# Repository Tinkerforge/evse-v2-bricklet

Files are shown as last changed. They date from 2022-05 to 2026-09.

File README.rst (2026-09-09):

EVSE Bricklet 2.0
=================

This Bricklet together with the ESP32 Ethernet Brick and the NFC Bricklet
form the hardware used in the WARP2 Charger.

The Firmware for the EVSE Bricklet 2.0 is also used for the EVSE Bricklet 3.0:
https://github.com/Tinkerforge/evse-v3-bricklet. The hardware version is
run-time detected.

See https://www.warp-charger.com/ for more details about WARP Charger.

This repository contains the firmware source code and the hardware design
files. The documentation generator configs can be found at
https://github.com/Tinkerforge/generators

.. BEGIN WARP REPOSITORIES (managed block, generated from esp32-firmware/repo_overview.rst - do not edit by hand, run update_repo_overview.py instead)

WARP Repositories
-----------------

This is an overview of all repositories that make up the WARP Charger and
WARP Energy Manager ecosystem.

Please report **any** issue concerning WARP hard- or software in the
`esp32-firmware`_ repository, no matter which repository it originates from.

Software
~~~~~~~~

- `esp32-firmware`_ - Source code of the ESP32 firmware shared between all WARP Chargers and Energy Managers

Libraries used by the firmware:

- `tfjson`_ - SAX style JSON serializer and deserializer
- `tfnetwork`_ - Modbus TCP server and client implementation
- `tfocpp`_ - OCPP 1.6 implementation
- `tftools`_ - Miscellaneous tools and helpers

Remote access:

- `esp32-remote-access`_ - Source code of the my.warp-charger.com remote access server

Documentation, tools and integrations:

- `warp-charger`_ - Source code of (docs.)warp-charger.com and the printed manual, released firmwares, datasheets and documents, as well as some tools and hardware design files
- `api.warp-charger.com`_ - Serves APIs that are used by WARP Chargers to obtain relevant public information like day ahead prices
- `vislog.warp-charger.com`_ - Visualizes WARP Charger logs and EVSE debug protocols
- `dbus-warp-charger`_ - Integrates WARP Chargers into a Victron Energy Venus OS device (e.g. Cerbo GX)

WARP Charger Hardware
~~~~~~~~~~~~~~~~~~~~~~

WARP4 Charger
"""""""""""""

*Current charger generation.*

- `warp-esp32-ethernet-v2-brick`_ - Hardware design files of the WARP ESP32 Ethernet Brick 2.0
- `warp-esp32-ethernet-v2-co-bricklet`_ - Firmware source code of the WARP ESP32 Ethernet 2.0 Co Bricklet (co-processor)
- `evse-v4-bricklet`_ - Hardware design files of the EVSE 4.0 Bricklet (firmware shared with the EVSE 2.0 Bricklet)
- `nfc-bricklet`_ - Firmware source code and hardware design files of the NFC Bricklet

WARP3 Charger
"""""""""""""

- `warp-esp32-ethernet-brick`_ - Hardware design files of the WARP ESP32 Ethernet Brick
- `evse-v3-bricklet`_ - Hardware design files of the EVSE 3.0 Bricklet (firmware shared with the EVSE 2.0 Bricklet)
- `nfc-bricklet`_ - Firmware source code and hardware design files of the NFC Bricklet

WARP2 Charger
"""""""""""""

- `esp32-ethernet-brick`_ - Hardware design files of the ESP32 Ethernet Brick
- `evse-v2-bricklet`_ - Firmware source code and hardware design files of the EVSE 2.0 Bricklet
- `nfc-bricklet`_ - Firmware source code and hardware design files of the NFC Bricklet

WARP1 Charger
"""""""""""""

- `esp32-brick`_ - Hardware design files of the ESP32 Brick
- `evse-bricklet`_ - Firmware source code and hardware design files of the EVSE Bricklet
- `rs485-bricklet`_ - Firmware source code and hardware design files of the RS485 Bricklet

WARP Energy Manager Hardware
~~~~~~~~~~~~~~~~~~~~~~~~~~~~~~

WARP Energy Manager 2.0
"""""""""""""""""""""""

*Current energy manager generation.*

- `esp32-ethernet-brick`_ - Hardware design files of the ESP32 Ethernet Brick
- `warp-energy-manager-v2-bricklet`_ - Firmware source code and hardware design files of the WARP Energy Manager 2.0 Bricklet
- `warp-front-panel-bricklet`_ - Firmware source code and hardware design files of the WARP Front Panel Bricklet

WARP Energy Manager 1.0
"""""""""""""""""""""""

- `esp32-ethernet-brick`_ - Hardware design files of the ESP32 Ethernet Brick
- `warp-energy-manager-bricklet`_ - Firmware source code and hardware design files of the WARP Energy Manager Bricklet

Forked/patched projects
~~~~~~~~~~~~~~~~~~~~~~~~~

- `arduino-esp32`_
- `esp32-arduino-libs`_
- `WireGuard-ESP32-Arduino`_

.. Link targets: One definition per repository, keep in sync with the lists above.

.. _esp32-firmware: https://github.com/Tinkerforge/esp32-firmware
.. _tfjson: https://github.com/Tinkerforge/tfjson
.. _tfnetwork: https://github.com/Tinkerforge/tfnetwork
.. _tfocpp: https://github.com/Tinkerforge/tfocpp
.. _tftools: https://github.com/Tinkerforge/tftools
.. _esp32-remote-access: https://github.com/Tinkerforge/esp32-remote-access
.. _warp-charger: https://github.com/Tinkerforge/warp-charger
.. _api.warp-charger.com: https://github.com/Tinkerforge/api.warp-charger.com
.. _vislog.warp-charger.com: https://github.com/Tinkerforge/vislog.warp-charger.com
.. _dbus-warp-charger: https://github.com/Tinkerforge/dbus-warp-charger
.. _warp-esp32-ethernet-v2-brick: https://github.com/Tinkerforge/warp-esp32-ethernet-v2-brick
.. _warp-esp32-ethernet-v2-co-bricklet: https://github.com/Tinkerforge/warp-esp32-ethernet-v2-co-bricklet
.. _evse-v4-bricklet: https://github.com/Tinkerforge/evse-v4-bricklet
.. _nfc-bricklet: https://github.com/Tinkerforge/nfc-bricklet
.. _warp-esp32-ethernet-brick: https://github.com/Tinkerforge/warp-esp32-ethernet-brick
.. _evse-v3-bricklet: https://github.com/Tinkerforge/evse-v3-bricklet
.. _esp32-ethernet-brick: https://github.com/Tinkerforge/esp32-ethernet-brick
.. _evse-v2-bricklet: https://github.com/Tinkerforge/evse-v2-bricklet
.. _esp32-brick: https://github.com/Tinkerforge/esp32-brick
.. _evse-bricklet: https://github.com/Tinkerforge/evse-bricklet
.. _rs485-bricklet: https://github.com/Tinkerforge/rs485-bricklet
.. _warp-energy-manager-v2-bricklet: https://github.com/Tinkerforge/warp-energy-manager-v2-bricklet
.. _warp-front-panel-bricklet: https://github.com/Tinkerforge/warp-front-panel-bricklet
.. _warp-energy-manager-bricklet: https://github.com/Tinkerforge/warp-energy-manager-bricklet
.. _arduino-esp32: https://github.com/Tinkerforge/arduino-esp32
.. _esp32-arduino-libs: https://github.com/Tinkerforge/esp32-arduino-libs
.. _WireGuard-ESP32-Arduino: https://github.com/Tinkerforge/WireGuard-ESP32-Arduino

.. END WARP REPOSITORIES

Repository Content
------------------

software/:
 * examples/: Examples for all supported languages
 * build/: Compiled files
 * src/: Source code of firmware
 * Makefile: Makefile to build project

hardware/:
 * Contains KiCad project files and additionally schematics as PDF

datasheets/:
 * Contains datasheets for sensors and complex ICs that are used

Hardware
--------

The hardware is designed with the open source EDA Suite KiCad
(http://www.kicad.org). Before you are able to open the files,
you have to install the Tinkerforge kicad-libraries
(https://github.com/Tinkerforge/kicad-libraries). You can either clone
them directly in hardware/ or clone them in a separate folder and
symlink them into hardware/
(ln -s kicad_path/kicad-libraries project_path/hardware). After that you
can open the .pro file in hardware/ with KiCad and from there view and
modify the schematics and the PCB layout.

Software
--------

If you want to do your own Brick/Bricklet firmware development we highly
recommend that you use our build environment setup script and read the
tutorial (https://www.tinkerforge.com/en/doc/Tutorials/Tutorial_Build_Environment/Tutorial.html).

To compile the C code we recommend you to install the newest GNU Arm Embedded
Toolchain (https://launchpad.net/gcc-arm-embedded/+download).
You also need to install bricklib2 (https://github.com/Tinkerforge/bricklib2).

You can either clone it directly in software/src/ or clone it in a
separate folder and symlink it into software/src/
(ln -s bricklib_path/bricklib2 project_path/software/src/). Finally make sure to
have CMake installed (http://www.cmake.org/cmake/resources/software.html).

After that you can build the firmware by invoking make in software/.
The firmware (.zbin) can then be found in software/build/ and uploaded
with brickv (click button "Flashing" on start screen).

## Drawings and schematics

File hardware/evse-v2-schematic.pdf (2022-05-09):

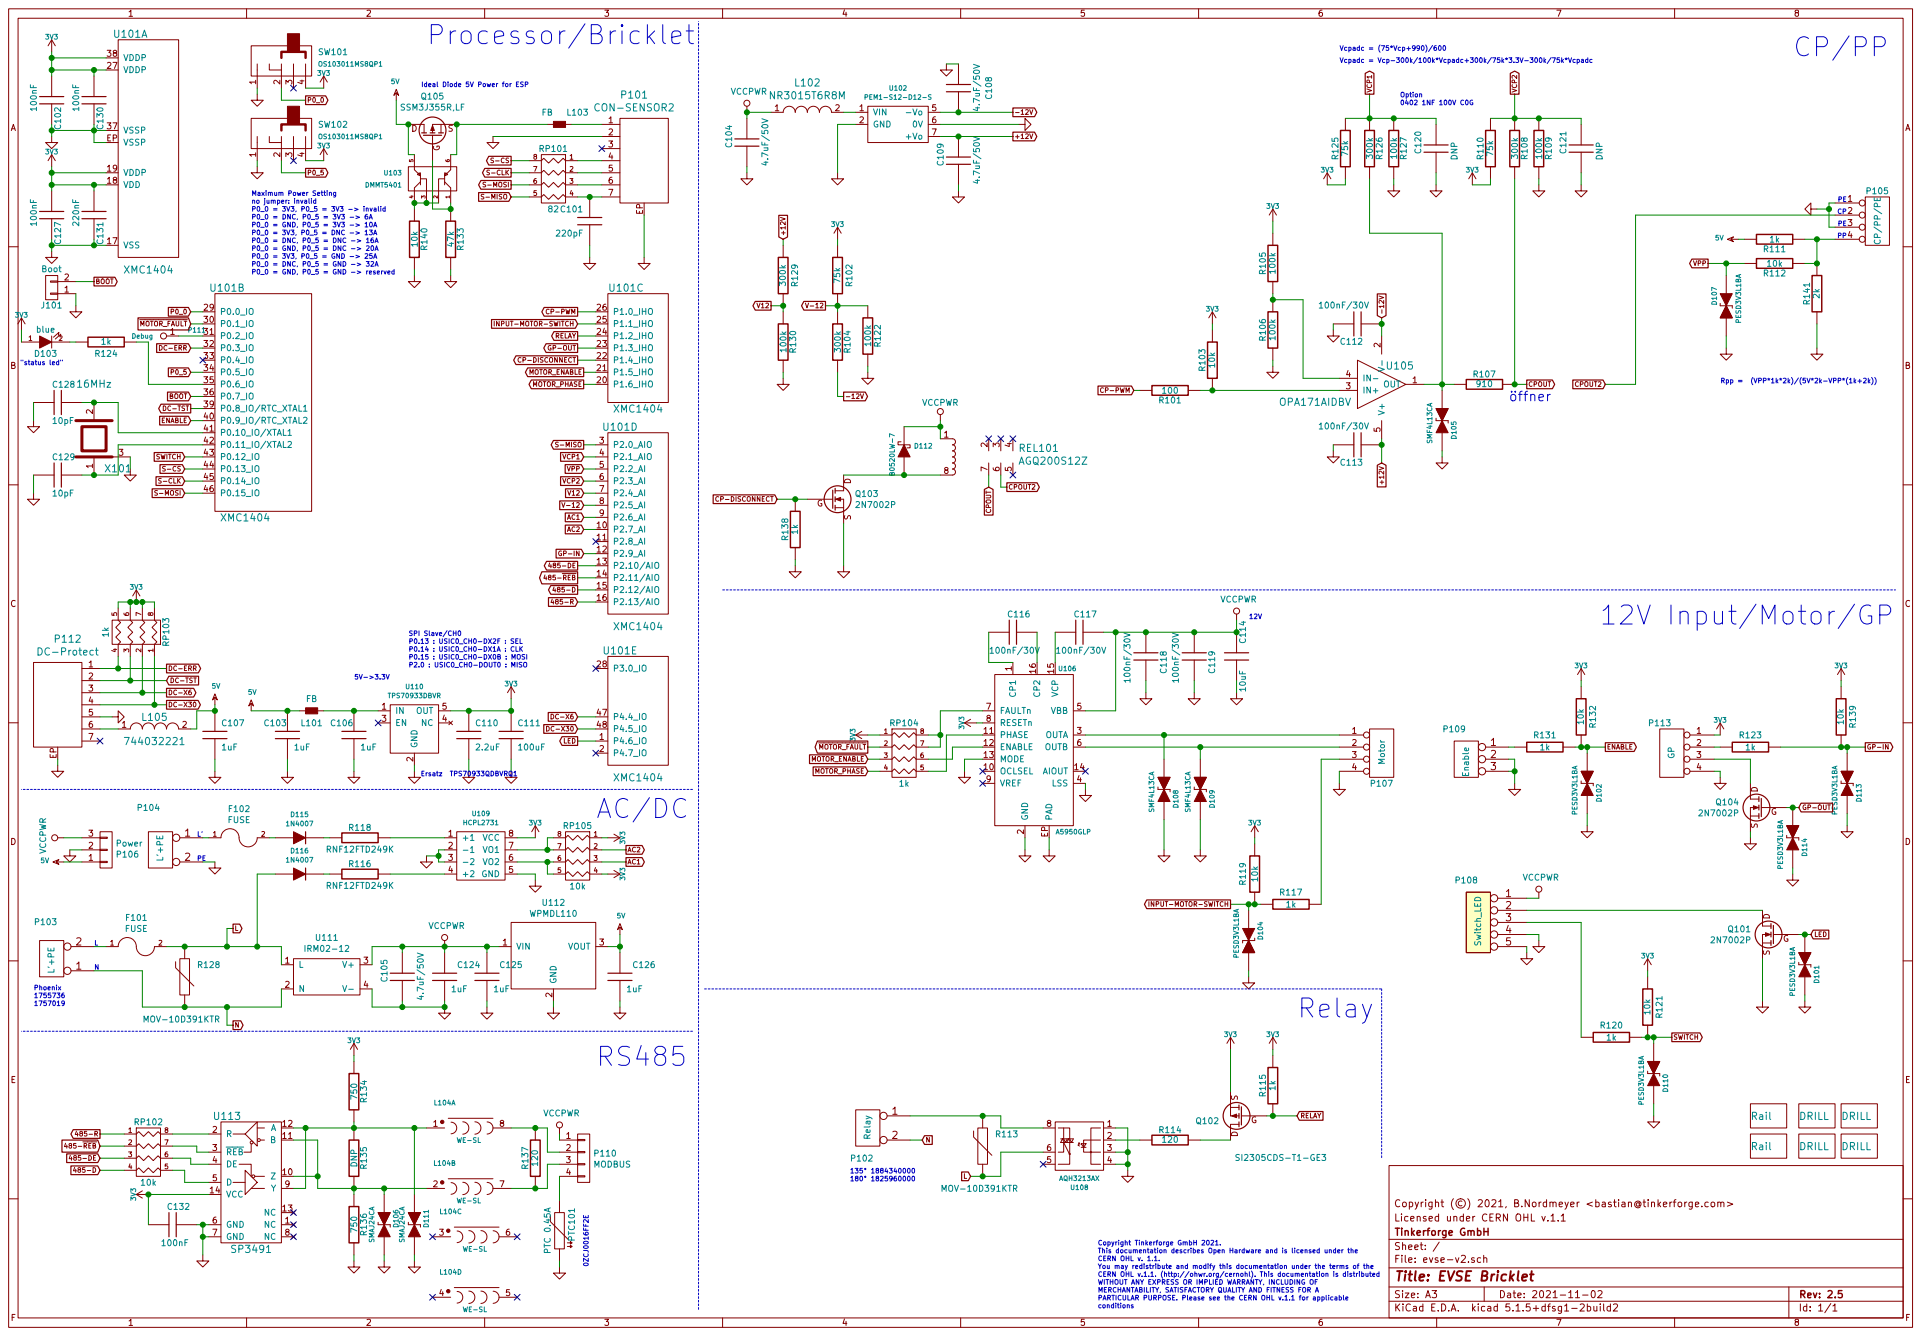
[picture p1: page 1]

Vcpadc = (75*Vcp+990)/600 Option
Vcpadc = Vcp-300k/100k*Vcpadc+300k/75k*3.3V-300k/75k*Vcpadc

Licensed under CERN OHL v.1.1 Copyright (©) 2021, B.Nordmeyer <bastian@tinkerforge.com> C130100nF

Ideal Diode 5V Power for ESP

Maximum Power Setting
no jumper: invalid P0_0 = 3V3, P0_5 = 3V3 -> invalid P0_0 = DNC, P0_5 = 3V3 -> 6A

CP-DISCONNECT

1 OCLSEL 10 PHASE 11 ENABLE 12 MODE 13 AIOUT 14 VCP 15 CP2 16 GND

Id: 1/1 Title: EVSE Bricklet File: evse-v2.sch Sheet: / Tinkerforge GmbH

Copyright Tinkerforge GmbH 2021. This documentation describes Open Hardware and is licensed under the CERN OHL v. 1.1. You may redistribute and modify this documentation under the terms of the CERN OHL v.1.1. (http://ohwr.org/cernohl). This documentation is distributed WITHOUT ANY EXPRESS OR IMPLIED WARRANTY, INCLUDING OF MERCHANTABILITY, SATISFACTORY QUALITY AND FITNESS FOR A

PARTICULAR PURPOSE. Please see the CERN OHL v.1.1 for applicable
conditions

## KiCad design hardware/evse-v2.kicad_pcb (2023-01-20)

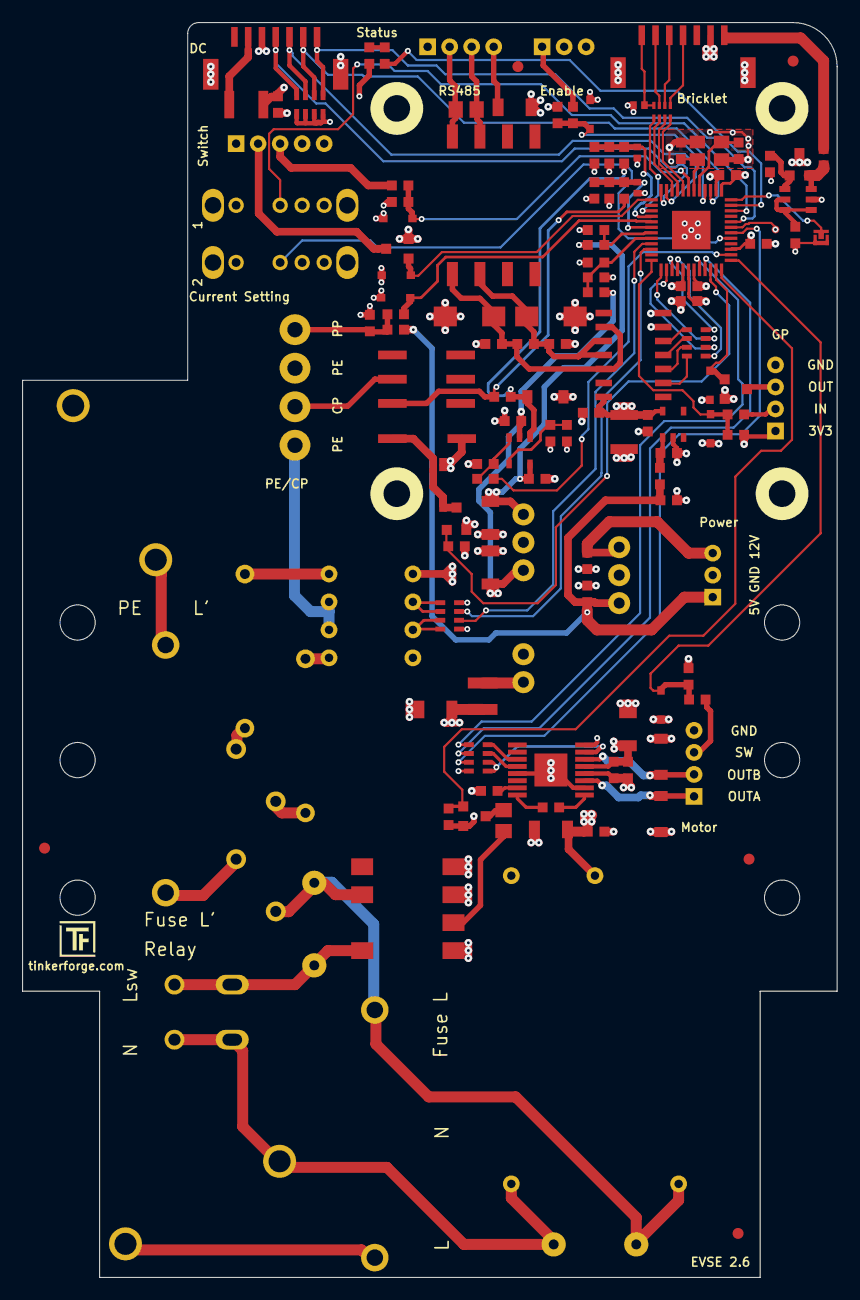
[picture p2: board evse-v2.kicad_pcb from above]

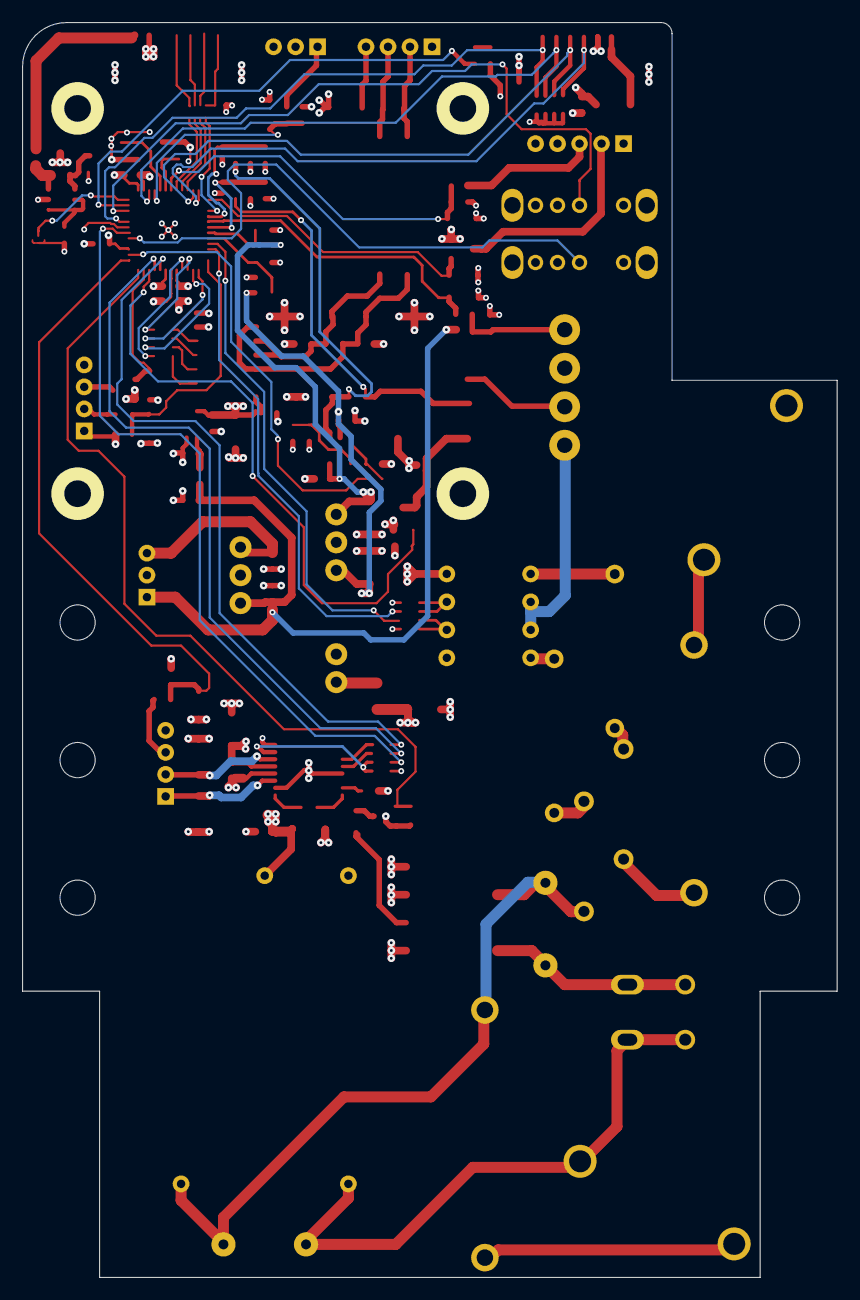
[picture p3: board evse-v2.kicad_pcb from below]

Board: 4 copper layers, 74.0 x 114.0 mm, 144 parts (2 on the bottom side), 100 nets.

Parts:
A101, A102, A103, A104: DRILL; DRILL_NP_35
A105, A106: Rail; din-rail-mount
C101: 220pF; C0402F
C102, C127, C130, C132: 100nF; C0603F
C103, C106, C107, C124, C125, C126: 1uF; C0603F
C104, C105, C108, C109: 4.7uF/50V; C1206
C110: 2.2uF; C0603F
C111: 100uF; C1210
C112, C113, C116, C117, C118, C119: 100nF/30V; C0603F
C114: 10uF; C1206
C120, C121: DNP; C0402F
C128, C129: 10pF; C0603F
C131: 220nF; C0603F
D101, D102, D104, D107, D110, D113, D114: ‎PESD3V3L1BA; SOD-323
D103: blue; D0603F
D105, D108, D109: SMF4L13CA; SOD-123FL
D106, D111: SMAJ24CA; DO-214AC
D112: B0520LW-7; SOD-123
D115, D116: 1N4007; DO-41
F101, F102: FUSE; Fuse-Holder-5x20
Fiducial_Mark: VAL**; Fiducial_Mark
Fiducial_Mark#2, Fiducial_Mark#3, Fiducial_Mark#4, Fiducial_Mark#5: VAL**; Fiducial_Mark
J101: Boot; SolderJumper
L101, L103: FB; R0603F
L102: NR3015T6R8M; NR3030
L104: WE-SL
P101: CON-SENSOR2; CON-SENSOR2_180
P102: Relay; LSF-SMT-500-02-135
P103, P104: L'+PE; wm_2491620000
P105: CP/PP/PE; OQ_4P_Vertical
P106: Power; JST-PH-3-THT
P107: Motor; JST-PH-4-THT
P108: Switch_LED; JST-PH-5-THT
P109: Enable; JST-PH-3-THT
P110: MODBUS; JST-PH-4-THT
P111: Debug; DEBUG_PAD
P112: DC-Protect; CON-SENSOR2_180
P113: GP; JST-PH-4-THT
PTC101: PTC 0.45A; C1206
Q101, Q103, Q104: 2N7002P; SOT23GDS
Q102: SI2305CDS-T1-GE3; SOT23GDS
Q105: SSM3J355R,LF; SOT23GDS
R1: 0; R1210
R101: 100; R0603F
R102, R110, R125: 75k; R0603F
R103, R112, R119, R121, R132, R139, R140: 10k; R0603F
R104, R108, R126, R129: 300k; R0603F
R105, R106, R109, R122, R127, R130: 100k; R0603F
R107: 910; R0603F
R111, R115, R117, R120, R123, R124, R131, R138: 1k; R0603F
R113, R128: MOV-10D391KTR; VAR_10mm
R114, R137: 120; R0805E
R116, R118: RNF12FTD249K; RNF12-2
R133: 47k; R0603F
R134, R136: 750; R0603F
R135: DNP; R0603F
R141: 2k; R0603F
REL101: AGQ200S12Z; AGQ2X0
RP101: 82; 4X0402
RP102: 10k; 0603X4
RP103, RP104: 1k; 4X0603
RP105: 10k; 4X0603
SW101, SW102: OS103011MS8QP1
U101: XMC1404; QFN48-EP2
U102: PEM1-S12-D12-S; PEM1S
U103: DMMT5401; SOT26
U105: OPA171AIDBV; SOT23-5
U106: A5950GLP; TSSOP16_EP
U108: AQH3213AX; AQ-H
U109: HCPL2731; DIP-8
U110: TPS70933DBVR; SOT23-5
U111: IRM02-12; IRM02
U112: WPMDL110
U113: SP3491; SOIC-14_3.9x8.7mm_Pitch1.27mm
X101: 16MHz; CRYSTAL_3225

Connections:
3V3: C102.1, C110.1, C111.1, C127.1, C130.1, C131.1, C132.2, D103.1 (A), P113.1, Q102.S, R102.2, R103.2, R105.2, R110.1, R115.2, R119.2, R121.2, R125.1, R132.2, R134.1, R139.2, RP103.5 (R4), RP103.6 (R3), RP103.7 (R2), RP103.8 (R1), RP104.1, RP105.1, RP105.4, SW101.4, SW102.4, U101.18 (VDD), U101.19 (VDDP), U101.27 (VDDP), U101.38 (VDDP), U106.8 (RESETn), U109.8 (VCC), U110.5 (OUT), U113.14 (VCC)
5V: C103.1, C107.1, C126.1, L101.2, P106.1, Q105.D, R1.1, R111.2, U103.5, U112.3 (VOUT)
485-D: RP102.4, U101.15 (P2.12/AIO)
485-DE: RP102.3, U101.13 (P2.10/AIO)
485-R: RP102.1, U101.16 (P2.13/AIO)
485-~REB: RP102.2, U101.14 (P2.11/AIO)
+12V: C109.1, C113.2, R129.2, U102.7 (+Vo), U105.5 (V+)
-12V: C108.2, C112.2, R104.2, U102.5 (-Vo), U105.2 (V-)
AC1: RP105.3, U101.9 (P2.6_AI)
AC2: RP105.2, U101.10 (P2.7_AI)
BOOT: J101.2, U101.36 (P0.7_IO)
CP-DISCONNECT: Q103.G, R138.2, U101.22 (P1.4_IHO)
CP-PWM: R101.2, U101.26 (P1.0_IHO)
CPOUT: R107.2, R108.2, REL101.7
CPOUT2: P105.2, REL101.6
DC-ERR: P112.1, RP103.4, U101.32 (P0.3_IO)
DC-TST: P112.2, RP103.3, U101.39 (P0.8_IO/RTC_XTAL1)
DC-X6: P112.3, RP103.2, U101.47 (P4.4_IO)
DC-X30: P112.4, RP103.1, U101.48 (P4.5_IO)
ENABLE: D102.1 (A), R131.1, R132.1, U101.40 (P0.9_IO/RTC_XTAL2)
GND: C101.2, C102.2, C103.2, C104.2, C105.2, C106.2, C107.2, C108.1, C109.2, C110.2, C111.2, C112.1, C113.1, C114.2, C118.1, C119.1, C120.2, C121.2, C124.2, C125.2, C126.2, C127.2, C128.2, C129.2, C130.2, C131.2, C132.1, D101.2 (K), D102.2 (K), D104.1 (A), D105.2 (K), D106.2 (K), D107.1 (A), D108.2 (K), D109.2 (K), D110.2 (K), D111.2 (K), D113.2 (K), D114.2 (K), J101.1, P101.2, P101.EP, P104.2 (PM), P105.1, P105.3, P106.2, P107.4, P108.4, P108.5, P109.2 (PM), P109.3, P112.5, P112.EP, P113.4, PTC101.2, Q101.S, Q103.S, Q104.S, R106.1, R109.2, R122.2, R127.2, R130.2, R133.1, R136.2, R138.1, R140.1, R141.1, SW101.1, SW102.1, U101.17 (VSS), U101.37 (VSSP), U101.EP (VSSP), U102.2 (GND), U102.6 (0V), U106.2 (GND), U106.4 (LSS), U106.13 (MODE), U106.EP (PAD), U108.1, U108.3, U108.4, U109.2 (-1), U109.3 (-2), U109.5 (GND), U110.2 (GND), U111.4 (V-), U112.2 (GND), U113.6 (GND), U113.7 (GND), X101.3
GP-IN: D113.1 (A), R123.1, R139.1, U101.12 (P2.9_AI)
GP-OUT: D114.1 (A), Q104.G, U101.23 (P1.3_IHO)
INPUT-MOTOR-SWITCH: D104.2 (K), R117.1, R119.1, U101.25 (P1.1_IHO)
L: D116.1 (A), F101.2, R113.2, R128.1, U108.6, U111.1 (L)
LED: D101.1 (A), Q101.G, U101.1 (P4.6_IO)
MOTOR_ENABLE: RP104.3, U101.21 (P1.5_IHO)
MOTOR_PHASE: RP104.4, U101.20 (P1.6_IHO)
N: P102.2 (PM), P103.1, R128.2, U111.2 (N)
unnamed: C101.1, P101.7, RP101.4
unnamed: C106.1, L101.1, U110.1 (IN)
unnamed: C116.1, U106.16 (CP2)
unnamed: C116.2, U106.1 (CP1)
unnamed: C117.2, U106.15 (VCP)
unnamed: C128.1, U101.41 (P0.10_IO/XTAL1), X101.2
unnamed: C129.1, U101.42 (P0.11_IO/XTAL2), X101.1
unnamed: D103.2 (K), R124.2
unnamed: D105.1 (A), R107.1, R126.2, U105.1 (OUT)
unnamed: D106.1 (A), L104.2, R135.2, R136.1, U113.10 (Z), U113.11 (B)
unnamed: D108.1 (A), P107.1, U106.3 (OUTA)
unnamed: D109.1 (A), P107.2, U106.6 (OUTB)
unnamed: D111.1 (A), L104.1, R134.2, R135.1, U113.9 (Y), U113.12 (A)
unnamed: D112.1 (A), Q103.D, REL101.8
unnamed: D115.1 (A), F102.2
unnamed: D115.2 (K), R118.1
unnamed: D116.2 (K), R116.1
unnamed: F101.1, P103.2 (PM)
unnamed: F102.1, P104.1
unnamed: L102.2, U102.1 (VIN)
unnamed: L103.1, Q105.S, U103.6
unnamed: L103.2, P101.1
unnamed: L104.7, P110.3, R137.1
unnamed: L104.8, P110.2, R137.2
unnamed: P101.4, RP101.1
unnamed: P101.5, RP101.2
unnamed: P101.6, RP101.3
unnamed: P102.1, R113.1, U108.8
unnamed: P105.4, R111.1, R112.1, R141.2
unnamed: P107.3, R117.2
unnamed: P108.2, Q101.D
unnamed: P108.3, R120.2
unnamed: P109.1, R131.2
unnamed: P110.4, PTC101.1
unnamed: P111.1, U101.31 (P0.2_IO)
unnamed: P112.6, R1.2
unnamed: P113.2, R123.2
unnamed: P113.3, Q104.D
unnamed: Q102.D, R114.1
unnamed: Q105.G, R133.2, U103.1
unnamed: R101.1, R103.1, U105.3 (IN+)
unnamed: R105.1, R106.2, U105.4 (IN-)
unnamed: R114.2, U108.2
unnamed: R116.2, U109.4 (+2)
unnamed: R118.2, U109.1 (+1)
unnamed: R124.1, U101.35 (P0.6_IO)
unnamed: R140.2, U103.2, U103.3, U103.4
unnamed: RP102.5 (R4), U113.5 (D)
unnamed: RP102.6 (R3), U113.4 (DE)
unnamed: RP102.7 (R2), U113.3 (~REB)
unnamed: RP102.8 (R1), U113.2 (R)
unnamed: RP104.5 (R4), U106.11 (PHASE)
unnamed: RP104.6 (R3), U106.12 (ENABLE)
unnamed: RP104.7 (R2), RP104.8 (R1), U106.7 (FAULTn)
unnamed: RP105.5 (R4), RP105.6 (R3), U109.6 (VO2)
unnamed: RP105.7 (R2), RP105.8 (R1), U109.7 (VO1)
P0_0: SW101.2, U101.29 (P0.0_IO)
P0_5: SW102.2, U101.34 (P0.5_IO)
RELAY: Q102.G, R115.1, U101.24 (P1.2_IHO)
S-CLK: RP101.7 (R2), U101.45 (P0.14_IO)
S-CS: RP101.8 (R1), U101.44 (P0.13_IO)
S-MISO: RP101.5 (R4), U101.3 (P2.0_AIO)
S-MOSI: RP101.6 (R3), U101.46 (P0.15_IO)
SWITCH: D110.1 (A), R120.1, R121.1, U101.43 (P0.12_IO)
V12: R129.1, R130.1, U101.7 (P2.4_AI)
V-12: R102.1, R104.1, R122.1, U101.8 (P2.5_AI)
VCC: C104.1, C105.1, C114.1, C117.1, C118.2, C119.2, C124.1, C125.1, D112.2 (K), L102.1, P106.3, P108.1, P110.1, REL101.1, U106.5 (VBB), U111.3 (V+), U112.1 (VIN)
VCP1: C120.1, R125.2, R126.1, R127.1, U101.4 (P2.1_AIO)
VCP2: C121.1, R108.1, R109.1, R110.2, U101.6 (P2.3_AI)
VPP: D107.2 (K), R112.2, U101.5 (P2.2_AI)
~MOTOR_FAULT: RP104.2, U101.30 (P0.1_IO)

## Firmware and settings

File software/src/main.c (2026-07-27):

/* evse-v2-bricklet
 * Copyright (C) 2021 Olaf Lüke <olaf@tinkerforge.com>
 *
 * main.c: Initialization for EVSE Bricklet 2.0
 *
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
 * You should have received a copy of the GNU Lesser General Public
 * License along with this library; if not, write to the
 * Free Software Foundation, Inc., 59 Temple Place - Suite 330,
 * Boston, MA 02111-1307, USA.
 */

#include <stdio.h>
#include <stdbool.h>

#include "configs/config.h"

#include "bricklib2/bootloader/bootloader.h"
#include "bricklib2/hal/system_timer/system_timer.h"
#include "bricklib2/logging/logging.h"
#include "bricklib2/warp/rs485.h"
#include "bricklib2/warp/meter.h"
#include "bricklib2/warp/contactor_check.h"
#include "communication.h"

#include "evse.h"
#include "iec61851.h"
#include "lock.h"
#include "led.h"
#include "button.h"
#include "adc.h"
#include "dc_fault.h"
#include "charging_slot.h"
#include "hardware_version.h"
#include "phase_control.h"
#include "tmp1075n.h"
#include "eichrecht.h"
#include "plc.h"
#include "frequency.h"
#include "ove_r37.h"
#include "iskra_display.h"

int main(void) {
	logging_init();
	logd("Start EVSE Bricklet 2.0\n\r");

	hardware_version_init();
	communication_init();
	ove_r37_init(); // Keep before evse_init()
	evse_init();
	charging_slot_init();
	iec61851_init();
	lock_init();
	contactor_check_init();
	led_init();
	button_init();
	adc_init();
	dc_fault_init();
	rs485_init();
	meter_init();
	phase_control_init();
	tmp1075n_init();
	eichrecht_init();
	plc_init();
	frequency_init();
	iskra_display_init();

	while(true) {
		bootloader_tick();
		communication_tick();
		lock_tick();
		contactor_check_tick();
		led_tick();
		button_tick();
		adc_tick();
		evse_tick();
		dc_fault_tick();
		rs485_tick();
		meter_tick();
		charging_slot_tick();
		phase_control_tick();
		tmp1075n_tick();
		eichrecht_tick();
		plc_tick();
		frequency_tick();
		ove_r37_tick();
		iskra_display_tick();
	}
}

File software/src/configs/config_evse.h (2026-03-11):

/* evse-v2-bricklet
 * Copyright (C) 2021 Olaf Lüke <olaf@tinkerforge.com>
 *
 * config_evse.h: EVSE 2.0 config
 *
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
 * You should have received a copy of the GNU Lesser General Public
 * License along with this library; if not, write to the
 * Free Software Foundation, Inc., 59 Temple Place - Suite 330,
 * Boston, MA 02111-1307, USA.
 */

#ifndef CONFIG_EVSE_H
#define CONFIG_EVSE_H

#include "xmc_gpio.h"
#include "hardware_version.h"

#define EVSE_CP_PWM_SLICE_NUMBER          0

#define EVSE_CP_PWM_PIN_NUM               4
#define EVSE_CP_DISCONNECT_PIN_NUM        5
#define EVSE_INPUT_GP_PIN_NUM             6
#define EVSE_OUTPUT_GP_PIN_NUM            7
#define EVSE_SHUTDOWN_PIN_NUM             8
#define EVSE_CONFIG_JUMPER_PIN0_NUM       9
#define EVSE_CONFIG_JUMPER_PIN1_NUM       10
#define EVSE_CONTACTOR_PIN_NUM            11
#define EVSE_PHASE_SWITCH_PIN_NUM         12

#define EVSE_CP_PWM_PIN                   hardware_version_get_port(EVSE_CP_PWM_PIN_NUM),         hardware_version_get_pin(EVSE_CP_PWM_PIN_NUM)
#define EVSE_CP_DISCONNECT_PIN            hardware_version_get_port(EVSE_CP_DISCONNECT_PIN_NUM),  hardware_version_get_pin(EVSE_CP_DISCONNECT_PIN_NUM)
#define EVSE_INPUT_GP_PIN                 hardware_version_get_port(EVSE_INPUT_GP_PIN_NUM),       hardware_version_get_pin(EVSE_INPUT_GP_PIN_NUM)
#define EVSE_OUTPUT_GP_PIN                hardware_version_get_port(EVSE_OUTPUT_GP_PIN_NUM),      hardware_version_get_pin(EVSE_OUTPUT_GP_PIN_NUM)
#define EVSE_SHUTDOWN_PIN                 hardware_version_get_port(EVSE_SHUTDOWN_PIN_NUM),       hardware_version_get_pin(EVSE_SHUTDOWN_PIN_NUM)
#define EVSE_CONFIG_JUMPER_PIN0           hardware_version_get_port(EVSE_CONFIG_JUMPER_PIN0_NUM), hardware_version_get_pin(EVSE_CONFIG_JUMPER_PIN0_NUM)
#define EVSE_CONFIG_JUMPER_PIN1           hardware_version_get_port(EVSE_CONFIG_JUMPER_PIN1_NUM), hardware_version_get_pin(EVSE_CONFIG_JUMPER_PIN1_NUM)
#define EVSE_CONTACTOR_PIN                hardware_version_get_port(EVSE_CONTACTOR_PIN_NUM),      hardware_version_get_pin(EVSE_CONTACTOR_PIN_NUM)
#define EVSE_PHASE_SWITCH_PIN             hardware_version_get_port(EVSE_PHASE_SWITCH_PIN_NUM),   hardware_version_get_pin(EVSE_PHASE_SWITCH_PIN_NUM)

#define EVSE_V2_CP_PWM_PIN                P1_0
#define EVSE_V2_CP_DISCONNECT_PIN         P1_4
#define EVSE_V2_INPUT_GP_PIN              P2_9
#define EVSE_V2_OUTPUT_GP_PIN             P1_3
#define EVSE_V2_SHUTDOWN_PIN              P0_9
#define EVSE_V2_CONFIG_JUMPER_PIN0        P0_5
#define EVSE_V2_CONFIG_JUMPER_PIN1        P0_0
#define EVSE_V2_CONTACTOR_PIN             P1_2
#define EVSE_V2_PHASE_SWITCH_PIN          NULL, 0 // Not available

#define EVSE_V3_CP_PWM_PIN                P1_4
#define EVSE_V3_CP_DISCONNECT_PIN         P4_4
#define EVSE_V3_INPUT_GP_PIN              NULL, 0 // Not available
#define EVSE_V3_OUTPUT_GP_PIN             NULL, 0 // Not available
#define EVSE_V3_SHUTDOWN_PIN              P4_6
#define EVSE_V3_CONFIG_JUMPER_PIN0        P4_5
#define EVSE_V3_CONFIG_JUMPER_PIN1        P2_9
#define EVSE_V3_CONTACTOR_PIN             P1_6
#define EVSE_V3_PHASE_SWITCH_PIN          P1_5

#define EVSE_V4_PLC_RESET_PIN             P3_0

#endif

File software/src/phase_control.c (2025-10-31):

/* evse-v2-bricklet
 * Copyright (C) 2023 Olaf Lüke <olaf@tinkerforge.com>
 *
 * phase_control.c: Control switching between 1- and 3-phase
 *
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
 * You should have received a copy of the GNU Lesser General Public
 * License along with this library; if not, write to the
 * Free Software Foundation, Inc., 59 Temple Place - Suite 330,
 * Boston, MA 02111-1307, USA.
 */

#include "phase_control.h"
#include "configs/config_phase_control.h"
#include "configs/config_evse.h"

#include <string.h>

#include "bricklib2/hal/system_timer/system_timer.h"
#include "bricklib2/warp/meter.h"
#include "bricklib2/utility/util_definitions.h"

#include "xmc_gpio.h"
#include "hardware_version.h"
#include "iec61851.h"
#include "evse.h"
#include "adc.h"
#include "communication.h"

PhaseControl phase_control;

void phase_control_init(void) {
	const bool autoswitch_enabled_save        = phase_control.autoswitch_enabled;
	const uint8_t phases_connected_save       = phase_control.phases_connected;
	const uint8_t phase_switch_wait_time_save = phase_control.phase_switch_wait_time;

	memset(&phase_control, 0, sizeof(PhaseControl));
	phase_control.phases_connected = phases_connected_save;

	// Default is 3-phase, but we only use 1-phase if only 1 phase is connected
	phase_control.current   = phase_control.phases_connected;
	phase_control.requested = phase_control.phases_connected;

	phase_control.autoswitch_enabled     = autoswitch_enabled_save;
	phase_control.phase_switch_wait_time = phase_switch_wait_time_save;

	const XMC_GPIO_CONFIG_t pin_config_output_low = {
		.mode             = XMC_GPIO_MODE_OUTPUT_PUSH_PULL,
		.output_level     = XMC_GPIO_OUTPUT_LEVEL_LOW
	};
	const XMC_GPIO_CONFIG_t pin_config_output_high = {
		.mode             = XMC_GPIO_MODE_OUTPUT_PUSH_PULL,
		.output_level     = XMC_GPIO_OUTPUT_LEVEL_HIGH
	};

	if(phase_control.current == 1) {
		XMC_GPIO_Init(EVSE_PHASE_SWITCH_PIN, &pin_config_output_high);
	} else {
		XMC_GPIO_Init(EVSE_PHASE_SWITCH_PIN, &pin_config_output_low);
	}
}

// Check for auto-switch conditions
// We switch from 3-phase to 1-phase if the car is charging and only using one phase
void phase_control_tick_check_autoswitch(void) {
	if(!phase_control.autoswitch_enabled) {
		phase_control.autoswitch_time = 0;
		phase_control.autoswitch_done = true;
		phase_control.info            = 0;
		return;
	}

	// If a car is charging, it is configured to use 3-phase and a meter is available, we can auto-switch to 1-phase if the car is only using one phase
	if((iec61851.state == IEC61851_STATE_C) && (phase_control.current == 3) && (phase_control.requested == 3) && meter.available && !phase_control.autoswitch_done) {
		// If the car is charging already for at least two seconds
		if(system_timer_is_time_elapsed_ms(iec61851.last_state_change, 2000)) {
			// If the phase 1 uses more than 5A and phase 2 and 3 use less than 0.5A
			if((meter_register_set.CurrentL1ImExSum.f > 5.0f) && (meter_register_set.CurrentL2ImExSum.f < 0.5f) && (meter_register_set.CurrentL3ImExSum.f < 0.5f)) {
				if(phase_control.autoswitch_time == 0) {
					// If the autos-switch-timer was not yet started we start it
					phase_control.autoswitch_time = system_timer_get_ms();
				} else if(system_timer_is_time_elapsed_ms(phase_control.autoswitch_time, 30000)) {
					// All autoswitch conditions have been met for 30 seconds -> switch to 1-phase
					phase_control.requested       = 1;
					phase_control.current         = 1;
					phase_control.autoswitch_time = 0;
					phase_control.autoswitch_done = true;
					phase_control.info            = 1;
					if(hardware_version.is_v3 || hardware_version.is_v4) {
						XMC_GPIO_SetOutputHigh(EVSE_PHASE_SWITCH_PIN);
					}
				}
			} else {
				phase_control.autoswitch_time = 0;
				phase_control.info            = 0;
			}
		}
	// If a car is charging on WARP2, it is configured to use 1-phase and a meter is available, we can auto-switch to 3-phase if the car is using three phase
	} else if(hardware_version.is_v2 && (iec61851.state == IEC61851_STATE_C) && (phase_control.current == 1) && (phase_control.requested == 1) && meter.available && phase_control.autoswitch_done) {
		// If the car is charging already for at least two seconds
		if(system_timer_is_time_elapsed_ms(iec61851.last_state_change, 2000)) {
			// If the phase 1 uses more than 5A and phase 2 and 3 use less than 0.5A
			const uint8_t phases_active = ((meter_register_set.CurrentL1ImExSum.f >= 0.5f) ? 1: 0) +
			                              ((meter_register_set.CurrentL2ImExSum.f >= 0.5f) ? 1: 0) +
			                              ((meter_register_set.CurrentL3ImExSum.f >= 0.5f) ? 1: 0);
			if(phases_active > 1) {
				if(phase_control.autoswitch_time == 0) {
					// If the autos-switch-timer was not yet started we start it
					phase_control.autoswitch_time = system_timer_get_ms();
				} else if(system_timer_is_time_elapsed_ms(phase_control.autoswitch_time, 15000)) {
					// All autoswitch conditions have been met for 15 seconds -> switch back to 3-phase
					phase_control.requested       = 3;
					phase_control.current         = 3;
					phase_control.autoswitch_time = 0;
					phase_control.autoswitch_done = false;
					phase_control.info            = 2;
				}
			} else {
				phase_control.autoswitch_time = 0;
				phase_control.info            = 0;
			}
		}
	// If no car is connected and an auto-switch occurred, we go back to the original phase-state
	} else if((iec61851.state == IEC61851_STATE_A) && (phase_control.current == 1) && (phase_control.requested == 1) && phase_control.autoswitch_done) {
		phase_control.requested       = 3;
		phase_control.current         = 3;
		phase_control.autoswitch_time = 0;
		phase_control.autoswitch_done = false;
		phase_control.info            = 0;
		if(hardware_version.is_v3 || hardware_version.is_v4) {
			XMC_GPIO_SetOutputLow(EVSE_PHASE_SWITCH_PIN);
		}
	// If the phase state was changed externally and the car is not charging anymore we have to reset autoswitch_done
	} else if((iec61851.state == IEC61851_STATE_A) && phase_control.autoswitch_done) {
		phase_control.autoswitch_time = 0;
		phase_control.autoswitch_done = false;
		phase_control.info            = 0;
	} else {
		phase_control.autoswitch_time = 0;
	}
}
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

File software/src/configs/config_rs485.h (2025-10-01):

/* evse-v2-bricklet
 * Copyright (C) 2021 Olaf Lüke <olaf@tinkerforge.com>
 *
 * config_rs485.h: RS485 communication config
 *
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
 * You should have received a copy of the GNU Lesser General Public
 * License along with this library; if not, write to the
 * Free Software Foundation, Inc., 59 Temple Place - Suite 330,
 * Boston, MA 02111-1307, USA.
 */

#ifndef CONFIG_RS485_H
#define CONFIG_RS485_H

#include "xmc_common.h"
#include "xmc_gpio.h"
#include "xmc_uart.h"
#include "xmc_scu.h"

#define RS485_USIC_CHANNEL        USIC1_CH1
#define RS485_USIC                XMC_UART1_CH1

#define RS485_RX_PIN              P2_13
#define RS485_RX_INPUT            XMC_UART_CH_INPUT_RXD // UART input stage DX0
#define RS485_RX_SOURCE           0b011 // DX0D

#define RS485_TX_PIN              P2_12
#define RS485_TX_PIN_AF           (XMC_GPIO_MODE_OUTPUT_PUSH_PULL_ALT7 | P2_12_AF_U1C1_DOUT0)

#define RS485_NRXE_PIN            P2_11
#define RS485_TXE_PIN             P2_10

#define RS485_NRXE_AND_TXE_PORT   XMC_GPIO_PORT2
#define RS485_NRXE_PIN_NUM        11
#define RS485_TXE_PIN_NUM         10

#define RS485_SERVICE_REQUEST_RX  2  // receive
#define RS485_SERVICE_REQUEST_TX  3  // transfer
#define RS485_SERVICE_REQUEST_TFF 4  // transfer frame finished
#define RS485_SERVICE_REQUEST_RXA 5  // alternate receive (parity error)

// Make sure that the priorities are as follows
// RX > TX = TFF
// TFF should never displace TX. TFF is unnecessary if we are in TX IRQ
// TX should never displace TFF. This would be a race condition
// RX interrupt will never be issued if TXE is set. If we are receiving a message,
// TX should never interrupt RX (we would lose data in this case)
// For full-duplex there is no TFF and RX should be higher priority then TX
#define RS485_IRQ_RX              11
#define RS485_IRQ_RX_PRIORITY     0
#define RS485_IRQCTRL_RX          XMC_SCU_IRQCTRL_USIC1_SR2_IRQ11

#define RS485_IRQ_TX              12
#define RS485_IRQ_TX_PRIORITY     1
#define RS485_IRQCTRL_TX          XMC_SCU_IRQCTRL_USIC1_SR3_IRQ12

#define RS485_IRQ_TFF             13
#define RS485_IRQ_TFF_PRIORITY    1
#define RS485_IRQCTRL_TFF         XMC_SCU_IRQCTRL_USIC1_SR4_IRQ13

#define RS485_IRQ_RXA             14
#define RS485_IRQ_RXA_PRIORITY    0
#define RS485_IRQCTRL_RXA         XMC_SCU_IRQCTRL_USIC1_SR5_IRQ14


#define RS485_RX_HANDLER     IRQ_Hdlr_11
#define RS485_RX_FIFO_POS    0
#define RS485_RX_FIFO_LENGTH XMC_USIC_CH_FIFO_SIZE_32WORDS
#define RS485_RX_FIFO_LIMIT  16
#define RS485_TX_HANDLER     IRQ_Hdlr_12
#define RS485_TX_FIFO_POS    32
#define RS485_TX_FIFO_LENGTH XMC_USIC_CH_FIFO_SIZE_32WORDS
#define RS485_TX_FIFO_LIMIT  16
#define RS485_BUFFER_SIZE    (512*2)

#endif

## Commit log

2021-03-04 add prototype of evse 2.0
    [evse-v2.kicad_pcb, evse-v2.sch]
2021-03-04 specify mosfet
    [evse-v2.kicad_pcb, evse-v2.sch]
2021-03-04 drc check
    [evse-v2.kicad_pcb]
2021-03-04 add hint
    [evse-v2.kicad_pcb]
2021-03-08 fix stuff
    [evse-v2.sch]
2021-03-12 fix schematic: dc pwm
    [evse-v2.sch]
2021-03-12 fix footprint
    [evse-v2.kicad_pcb]
2021-03-18 add todos
    [evse-v2.kicad_pcb]
2021-04-08 start working at version 2.1
    changes:
    * remove dc protector connector for alc
    * move relay connector
    * Move PE/CP connector
    * move Fuse L, PE L' connector, R
    * add Logos
    * change PCB outline to give more space
    * move pcb edge connectors (enable etc.)
    * remove DC Protection PWM signal
    * add 220uH
    * fix relay footprint bug
    * move din rail mounting
    * move PCB drills
    [evse-v2.kicad_pcb, evse-v2.sch]
2021-04-08 add ideal diode
    [evse-v2.kicad_pcb, evse-v2.sch]
2021-04-08 detail improvements
    [evse-v2.kicad_pcb, evse-v2.sch]
2021-04-09 add pulldown for pp
    [evse-v2.kicad_pcb, evse-v2.sch]
2021-04-12 fix connector positions, make pcb 1mm shorter, add fiducials
    [evse-v2.kicad_pcb]
2021-04-13 ordered prototype
    [evse-v2.kicad_pcb]
2021-04-14 Add initial EVSE 2.0 firmware
    This is mostly a mix of the old EVSE 1.0 firmware and the RS485 modbus code.
    dc fault check and other new features mostly have testing code and are WIP.
    [cmake_config_custom.txt]
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2021-04-16 Add password for reset dc fault password function
    [communication.c]
2021-04-16 version 2.2: bugfix pullup relay
    [evse-v2.kicad_pcb, evse-v2.sch]
2021-04-16 bugfix p ch mosfet orientation relay
    [evse-v2.kicad_pcb, evse-v2.sch]
2021-04-16 swap naming ac1 and ac2
    [evse-v2.sch]
2021-04-16 The relay pin in EVSE 2.0 is active low instead of active high
2021-05-06 start evse 2.3
    * change 120 ohm footprint to 0805
    * move esd diode
    [evse-v2.kicad_pcb, evse-v2.sch]
2021-05-11 more changes
    change relay connector
    move connectors
    integrate inline diodes
    [evse-v2.kicad_pcb, evse-v2.sch]
2021-05-11 add connector hint
    [evse-v2.sch]
2021-05-17 change relay clamp
    [evse-v2.kicad_pcb, evse-v2.sch]
2021-05-25 add version 2.4
    5v back power supply for esp
    [evse-v2.kicad_pcb, evse-v2.sch]
2021-05-25 deleted unconnected trace / ordered prototype V2.4
    [evse-v2.kicad_pcb]
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2021-05-26 Disable lock by default (not used by WARP Charger)
    [config.h, evse.c, lock.c]
2021-06-02 Don't disable irq during adc calculation
    sum is not increased in irq anymore
2021-06-02 Use internal signals to trigger ADC
    We sync up two CCU40 slices and the second triggers ADC with fixed duty cycle
    [adc.c, evse.c]
2021-06-08 Trigger watchdog if we did not get a new result for adc channel 0 for 60 seconds.
    In this case something went horribly wrong, since the adc
    should be triggered automatically in the background at all times.
    [adc.c, adc.h]
2021-06-15 start version 2.5
    increase diode pitch
    change switch led connector position
    [evse-v2.kicad_pcb]
2021-06-15 change relay connector footprint
    [evse-v2.kicad_pcb, evse-v2.sch]
2021-06-15 fix sku numbers
    [evse-v2.sch]
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2021-08-05 Add DC Fault blinking code (3 times)
    This overwrites the old calibration error code. Calibration error
    is part of the new DC Fault error.
    [communication.h, dc_fault.c]
2021-08-06 Add support for low PWM measurements and detect diode error
    [adc.c, adc.h, communication.c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]
2021-08-06 Change timer from CCU40 to CCU41
    CCU40 is now completely used up by CP/PE PWM generation
2021-08-12 Use jumper config the other way around
    This way the current config is the same as with EVSE V1
2021-08-16 Use CCU41_CC40 and CCU41_CC41 for timer
    we had a collision with CP/PE PWM otherwise
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2021-08-18 Improve LED handling
    If LED state is currently LED_STATE_OFF or LED_STATE_ON we
    leave the LED where it is (and don't restart the standby timer).
    If LED state is currently in LED_STATE_API we
    turn the LED on (which brings it in LED_STATE_ON) and restarts the standby timer.
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2021-08-24 Fix button configuration bug (& vs |)
    [button.c]
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2021-09-01 Use 50x averaging for ADC value
    With 75x we sometimes don't satisfy the 100ms turn-off-time
    that is required by IEC61851
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2021-09-02 Fix copy and paste error
    I replaced "75" with adc_count, but there were some 75 that
    are part of a calculation and not the adc_count...
    [adc.c]
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2021-09-10 Fix off-by-one in energy meter values
    [config.h]
2021-09-29 Add some wait time in case of unexpected error
    This gives the energy meter some time to recover
2021-09-29 change rs485 bias resistor values
    [evse-v2.kicad_pcb, evse-v2.sch]
2021-10-06 Don't check EVSE_V2_BUTTON_CONFIGURATION_STOP_CHARGING in IEC61851 state machine
    "was_pressed" is only set if EVSE_V2_BUTTON_CONFIGURATION_STOP_CHARGING
    is not configured.
    Checking this here again can lead to an unstopable charging state...
2021-10-12 Calculate time since pwm change correctly
    [communication.c]
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2021-10-15 Add GetAllDataX API
    For internal use in WARP Charger only
    [communication.c, communication.h]
2021-10-20 Set charging time to 0 if in managed mode and max current is changed to 0
2021-10-25 Update KiCad link
    https://www.kicad.org/blog/2021/10/Avoid-links-to-former-kicad-domain/
2021-11-02 change drill diameters
    [evse-v2.kicad_pcb, evse-v2.sch]
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2021-11-25 Improve vehicle connected detection in case of error on startup
    [communication.c]
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2022-01-17 Make sure incomming/outgoing cable slots are set correctly
    [evse.h, iec61851.c, main.c]
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2022-01-17 Always reset button slot on disconnect
    If clear on disconnect is true it will be overwritten with 0 directly aftwards
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2022-02-21 Improve all data API segmentation
    Assume that the managed mode is configured in slot 7
    and apply the legacy configuration to it
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2022-06-07 Make sure to never start charging when button is pressed
    and during energy meter detection use SDM630 as default
2022-06-09 Fix bug with meter type detection for WARP2 Charger Smart
    meter type was detected as SDM630, even when no meter was connected...
    [config.h]
2022-06-28 Improve resolution of duty cycle calculation
    We now have a max current resolution of 1.25mA
2022-07-04 Make sure cp/pe and pp/pe resistances are properly initialized
    We don't want to be in error state for the fist 1ms after boot
    [adc.c]
2022-07-04 Add minimum time of 30s between error state E/F and next activation of contactor
    [iec61851.c]
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2022-07-06 Implement reset for button-press-boot-time
    [communication.c]
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2022-08-22 FIX bug in PP/PE voltage calculation
    [evse.c]
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2022-08-25 Imprive diode error check
    [iec61851.c]
2022-11-15 Make sure that control pilot disconnect does not zero user slot on accident
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2022-12-06 Make sure contactor is not turned off under load
    even if stop of charging is triggered by wallbox
2022-12-19 Handle/reset/mark as done ev wakeup in the proper IEC state
    [iec61851.c]
2023-01-13 Use correct meter value size
    [communication.c]
2023-01-19 Set contactor check invalid counter in case of emergency contactor shutdown (dc error)
    [dc_fault.c]
2023-01-20 Version 2.6: Upadated to Kicad 6. Changed L103 to 0 Ohm resistor.
    [evse-v2.kicad_pcb, evse-v2.kicad_sch, evse-v2.sch]
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2023-03-15 Use max current input configuration only when input is active (high or low)
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2023-04-27 Add blink led indicator code 2001-2010
    for custom error code with 1-10 "blink amount"
    [communication.c, config.h, led.c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]
2023-04-27 Add automatic DC fault test after each charging session
    and at least every 24h
2023-04-28 Fix external blink detection (new blink pattern is new activation)
    [led.c, led.h]
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2023-06-15 Move meter functionality to bricklib2/warp
    This is now shared with WARP Energy Manager Bricklet
    [communication.c, config.h, config_rs485.h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]
2023-06-15 Move contactor_check to bricklib2/warp
    [communication.c, config_contactor_check.h, dc_fault.c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]
2023-06-19 Fix relay inversion configuration
    [config_contactor_check.h]
2023-07-06 Fix read of stored startup value of boost mode
    [evse.c]
2023-07-07 User has to disconnect first for error state EF, but not for D
    [iec61851.c]
2023-08-21 Add CONTACTOR_PIN define for bricklib2 compatibility
    Some changes of the WARP3 branch did leak into the bricklib2.
    For now we just use both defines here (RELAY and CONTACTOR).
    Later when we merge the WARP3 branch the RELAY define will be removed.
    [config_evse.h]
2023-10-27 Add initial support for initial WARP3 test hardware
    [cmake_config_custom.txt]
2023-10-27 Fix errors in LED CCU8 configuration
    [config_led.h, led.c]
2023-10-27 Improve diode error detection
    [adc.c, adc.h, evse.c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]
2023-10-27 Increase version to 2.2.0 for WARP3 support chages
    [config.h]
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2023-10-31 Add stub implementation for TMP1075N temperature sensor
    Current hardware has it connected to wrong pins.
    Implementation will be finished when next prototype arrives.
    [config_tmp1075n.h, main.c, tmp1075n.c]
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2023-11-03 Fix pin mixup
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2023-11-06 Add support for 20mA AC fault current detection
    Note: This does not replace an AC RCD!
    [communication.h, dc_fault.c]
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2023-11-09 Fix parameter sequence copy+paste error
    [communication.h]
2023-11-10 Give the PE error the highest priority
    This is possible inn EVSE V3 since we can detect it explicitly.
    [iec61851.c]
2023-11-14 Fix I2C address
2023-11-14 Fix TMP1075N SDA source
    [config_tmp1075n.h]
2023-11-14 Read more then the expected value
    This ensures that the buffer is always empties if something goes wrong
    [tmp1075n.c]
2023-12-08 Add support for resetable relative import/export energy
    [communication.c, communication.h, evse.c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]
2023-12-19 Fix third check during dc fault calibration
    In third check both x6 and x30 need to be low. Before we only checked
    if at least one of them is low.
    [dc_fault.c]
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2024-01-09 Swap pins for VCP1 and VCP2
    [adc.c]
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2024-01-10 Every error state results in a charger state
    [communication.c, dc_fault.c]
2024-01-23 Make sure that the diode check is only run if at least one negative PWM value has been measured
    Otherwise, if the wallbox is restartet during a charging session,
    it is possible that the wallbox erroneously goes into an diode
    error for a few ms after startuo.
    [config.h, iec61851.c]
2024-01-29 Fix bug in DC fault detection debounce
    [config.h, dc_fault.c]
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2024-02-16 Fix GPIO copy+paste error
    [communication.c]
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2024-02-23 Make sure to use float instead of double
    Add compiler flag that throws an error in case of accidental double-promotion
    If we have doubles in the code the compiler will add
    additional function for addition, subtraction, division
    etc for double. We don't have enough flash for this.
    [evse.c, iec61851.c]
2024-02-23 Don't wait for car to stop charging in phase control state machine
    this is already done ine evse_set_output internally
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2024-03-05 Add phase info parameter
    The info parameter is set to 1 if 1-phase was forced by auto-switch
2024-03-07 Add API to enable/disable phase autoswitch
    this configuration is persistent on reboot
    [communication.c, communication.h, evse.c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]
2024-03-14 Fix LED colors for nag and error.
    Setting the error hue to orange was ignored anyway.
    [communication.c]
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2024-03-20 Add API to configure connected phases
    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
    [communication.c, communication.h, evse.c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]
2024-03-28 Fix phase control checks
    [communication.c, phase_control.c]
2024-04-04 Add main function to test and update bindings
    [full_test_v3.py]
2024-05-21 Make sure charging is stopped when button is pressed
    while wallbox is in IEC61851 state B2 ans started
    when wallbox is in IEC61851 state B1 if configured accordingly
2024-09-05 Make sure charging time is zeroed when car does not wake up again after phase change
2024-09-19 Make sure charging time is always started when IEC61851 state changes to C
2024-11-05 Increase wait time between phase switch and CP reconnect from 2s to 4s.
2024-11-05 Increase wait time for charge-restart after phase change from 3s to 10s
2024-11-18 Allow instant phase switch when car has not charged or cp was disconnected
2024-11-18 Fix whitespace
    Normally the Bricklet firmwares use tabs. Lots of spaces have
    crept into the EVSE firmware, convert it back to tabs.
    [adc.h, dc_fault.c, evse.h]
2024-11-20 Properly handle "instant_phase_switch_allowed" if a car is connected while rebooting
    [iec61851.c]
2024-11-22 Increase adc ignore results after cp re-connect from 2 counts to 4 counts
2024-11-28 Change time between phase switch and CP reconnect from 4s to 5s
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2024-12-05 Set external charging slot to enabled with 32A on first boot of 2.2.8
2025-02-06 Fix bug in detection of phases connected to meter
    [config.h, phase_control.c]
2025-06-03 Add support for 500ms wait time for C->B state change after duty cycle change
    fixes problems with hybrid BMWs
    [config.h, evse.c, evse.h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]
2025-06-03 Add support for longer phase switch wait time in case of EV charger hang-up
    possible fix for problems seen with Polestar chargers
    [evse.c, evse.h, phase_control.c]
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2025-07-08 Fix "maybe switch under load" flag reset
    [config.h, evse.c, iec61851.c]
2025-07-08 Fix "maybe switch under load" flag reset again...
    [iec61851.c]
2025-07-29 Change ADC integration time from 50ms to 25ms
    we want to have a higher sampling rate to be able to remove
    glitches in sate C -> B transation (see next commits)
    [adc.c]
2025-07-29 Improve B -> C and C -> B transition glitch rejection
    This sould also improve our handling of
    IEC 61851-1 table A.6 sequence 11 "EV signal to the EV supply equipment".
    [adc.h, evse.c, iec61851.c]
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2025-07-29 Ignore ADC results for 550ms after PWM change
    We have seen in several hybrid BMW cars that they have
    a 2700 ohm resistance glitch on the CP line after about
    500ms after a change of the duty cycle....
    We can skip the glitches by ignoring some adc results
    after PWM changes.
    [evse.c]
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2025-08-01 Properly handle transition time reset
    [iec61851.c]
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2025-09-01 Fix CP disconnect race condition that resulted in erroneous charger state
    [adc.c, iec61851.c]
2025-09-04 Add missing negation for disconnected check
    [iec61851.c]
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2025-10-01 Use correct signedness where possible and implicit casts otherwise
    [adc.c, adc.h, config_custom_bootloader.h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]
2025-10-01 Add missing break
    The break here is not strictly necessary, since we check for
    time-progress anyway
    [dc_fault.c]
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2025-10-07 Remove bogus ma != 1000 check
    This check doesn't make sense, it is never true.
    [phase_control.c]
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2025-10-30 Fix button_configuration check
2025-10-30 led: Fix h == 0, s != 0, v != 0 enumeration.
    [led.c]
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2025-11-02 Make sure cp can not stay disconnected when ev wakeup is reset
    [iec61851.c]
2026-01-22 Split General Information into Gateway Identification/Serial
    The sizes we need to support for OPCPP (41 and 25 byte) do not fit
    in a single 64 byte tfp message
    [communication.c, communication.h]
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2026-02-27 Add warp4 specific pp calculation
    [adc.c, iec61851.c]
2026-05-07 Fix WARP2 breathing bug
    [config.h, led.c]
2026-07-22 Fix boot, limit, symmetry handling after testing
    [communication.h, ove_r37.h]
2026-07-22 Fix implementation for OVE R 37 5.9.2 Prüfung B
    There was a misunderstanding of how this works. the start deleay is a
    randomized delay of 0..300s, not a configurable parameter.
    [communication.c, evse.c, ove_r37.h]
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2026-07-24 Use correct charging slot (off-by-2 to default)
    [communication.c]
2026-08-17 Fix CP PWM readback-racecondition
    [adc.c, adc.h, evse.c]
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2026-09-16 Save lock bit for non-eichrecht iskra meter on startup
    and fix race condition between fast read and backlight configuration
    [config.h]
2026-10-06 Only allow dc fault reset when no calibration running
    [communication.c]
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
